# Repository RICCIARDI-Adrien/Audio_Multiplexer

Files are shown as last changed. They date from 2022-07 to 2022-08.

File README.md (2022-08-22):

# Audio multiplexer

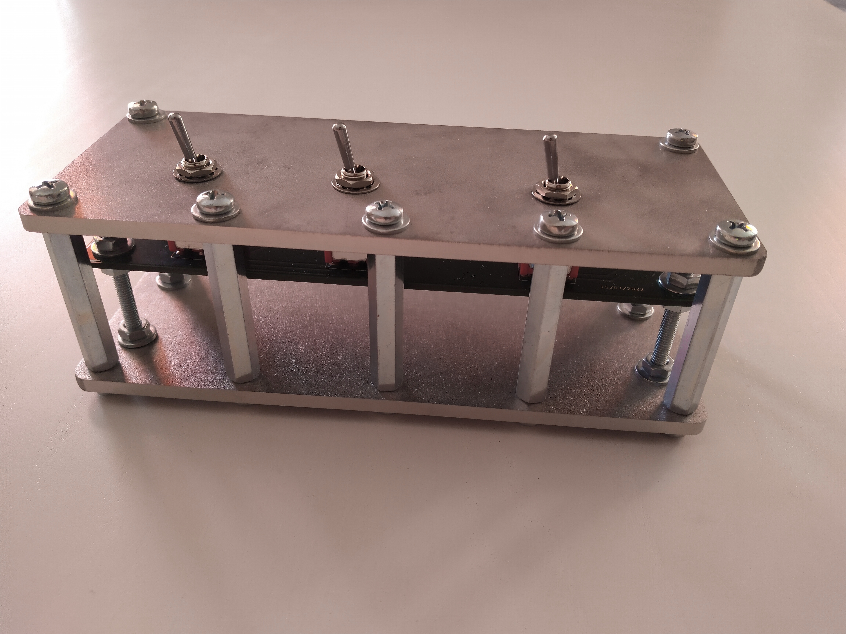
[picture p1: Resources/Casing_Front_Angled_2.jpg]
Casing front angled


## Description

A simple passive multiplexer providing :
* two 3.5mm jack inputs connected to two PC line outputs,
* two 3.5mm jack outputs connected to active speakers and a headset,
* one 3.5mm jack input connected to the headset microphone,
* two 3.5mm jack outputs connected to two PC microphone inputs.

```
                      +------+
             Line out |      | Mic in
     +----------------| PC 1 |<---------------+
     |                |      |                |
     |                +------+                |
     |                                        |
     |                +------+                |
     |       Line out |      | Mic in         |
     |   +------------| PC 2 |<-----------+   |
     |   |            |      |            |   |
     |   |            +------+            |   |
     |   |                                |   |
     v   v                                |   |
  +----------------------------------------------+             
  |              AUDIO MULTIPLEXER               |
  |                                              |
  |  Audio             Audio                Mic  |
  |   in                out                 in   |
  |                                              |
  +----------------------------------------------+
                       |  |                  ^
                       |  |                  |
                +------+  +-----+   +--------+
                |               |   |
                v               v   |
           +----------+      +---------+
           |          |      | Headset |
           | Speakers |      |  with   |
           |          |      |  mic    |
           +----------+      +---------+
```

The multiplexer microphone input is designed to be driven separately in case this is needed later.

## PCB

The PCB has been designed with KiCad 6.0.6.

Naked PCB :
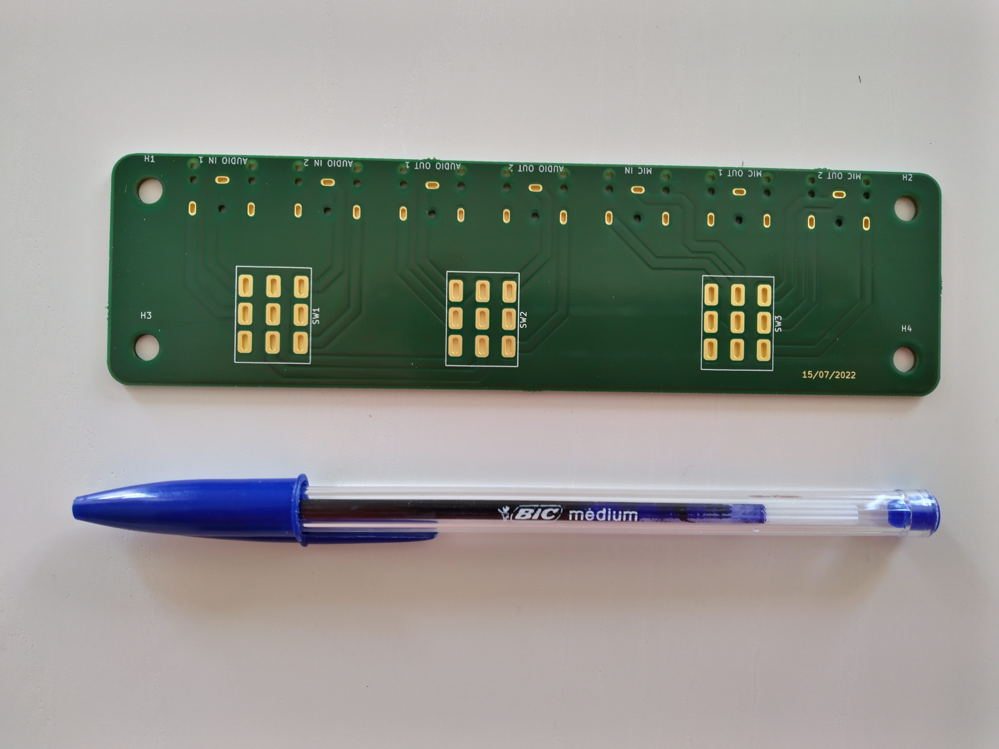
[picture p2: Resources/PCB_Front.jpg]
Naked PCB front view

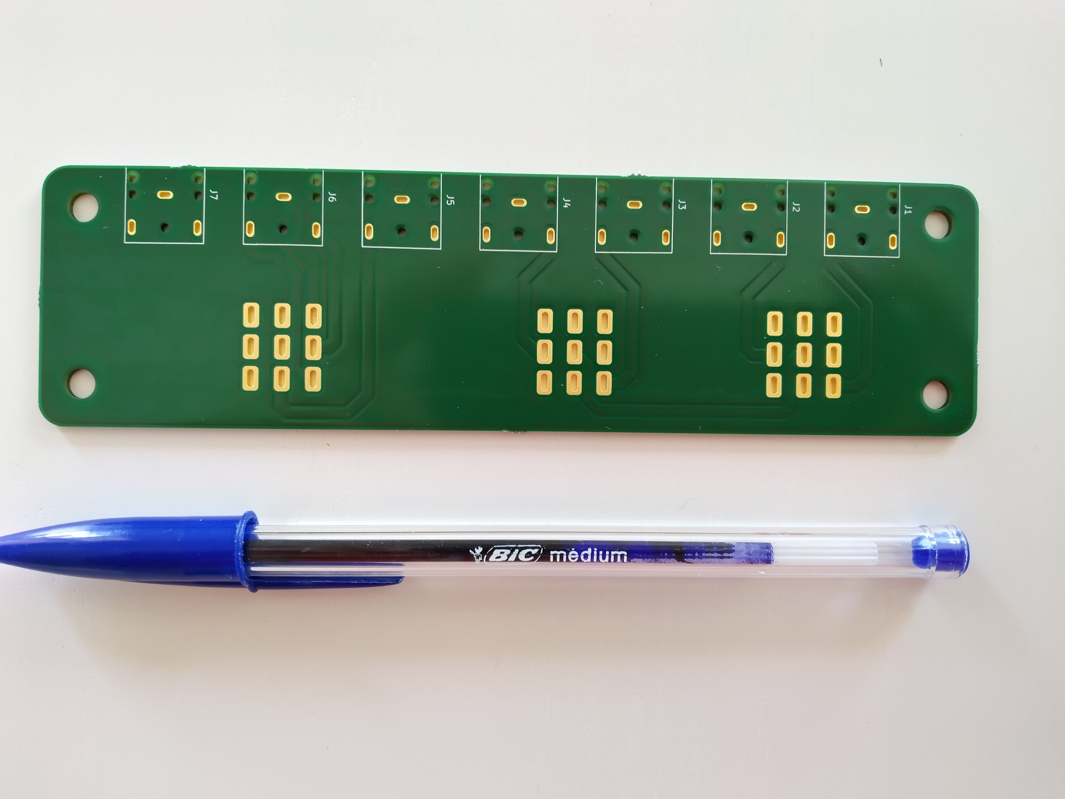
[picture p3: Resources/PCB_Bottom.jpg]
Naked PCB bottom view


Assembled PCB :
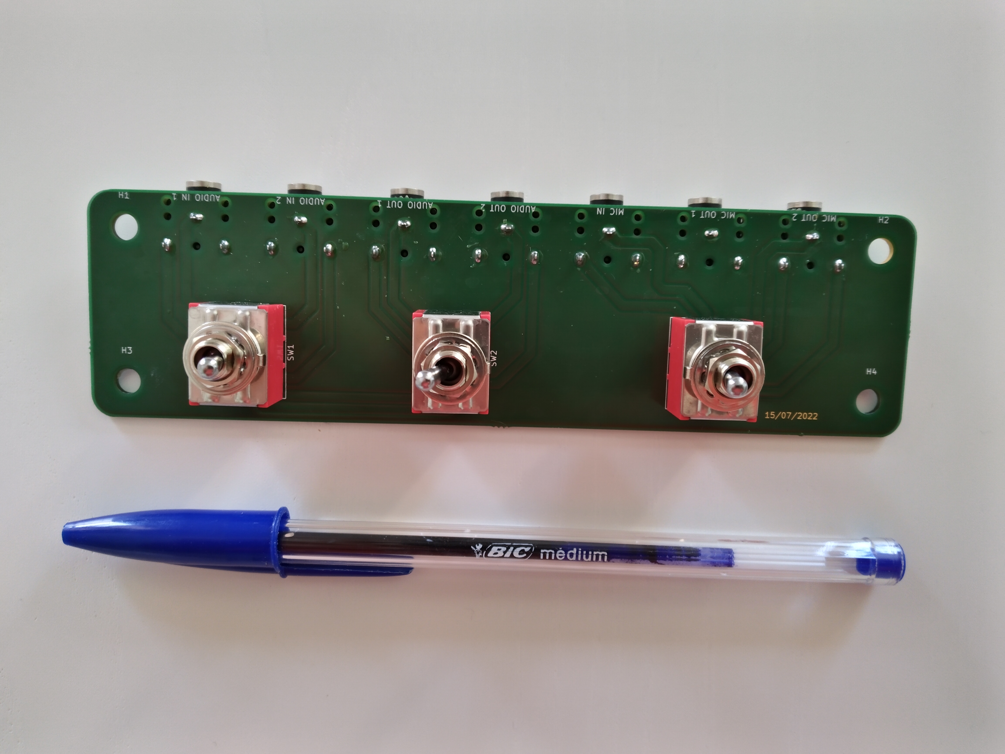
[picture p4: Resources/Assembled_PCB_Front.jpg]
Assembled PCB front view

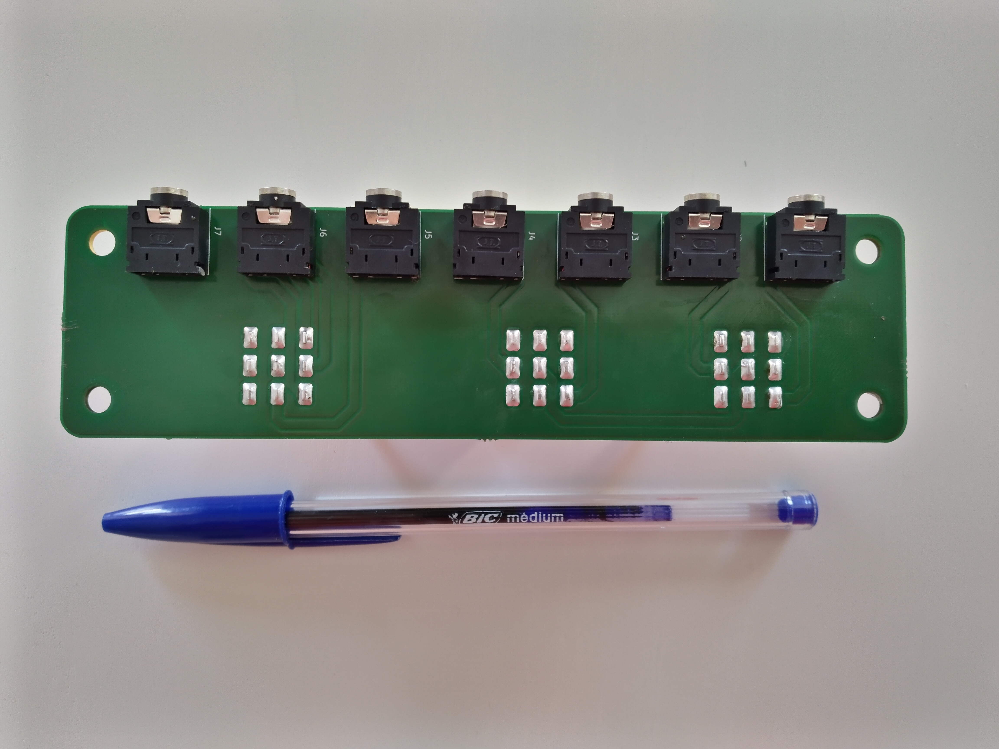
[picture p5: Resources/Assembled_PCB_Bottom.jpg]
Assembled PCB bottom view


## Casing

The casing has been designed with FreeCAD 0.19. The multiple DXF files generated by FreeCAD have been combined using LibreCAD 2.1.3.
The casing has been designed to be laser-cut in a 4-mm thick 304 stainless steel.

Steel plates :
Steel plates

Casing top :
Casing top

Casing bottom :
Casing bottom

Casing front :
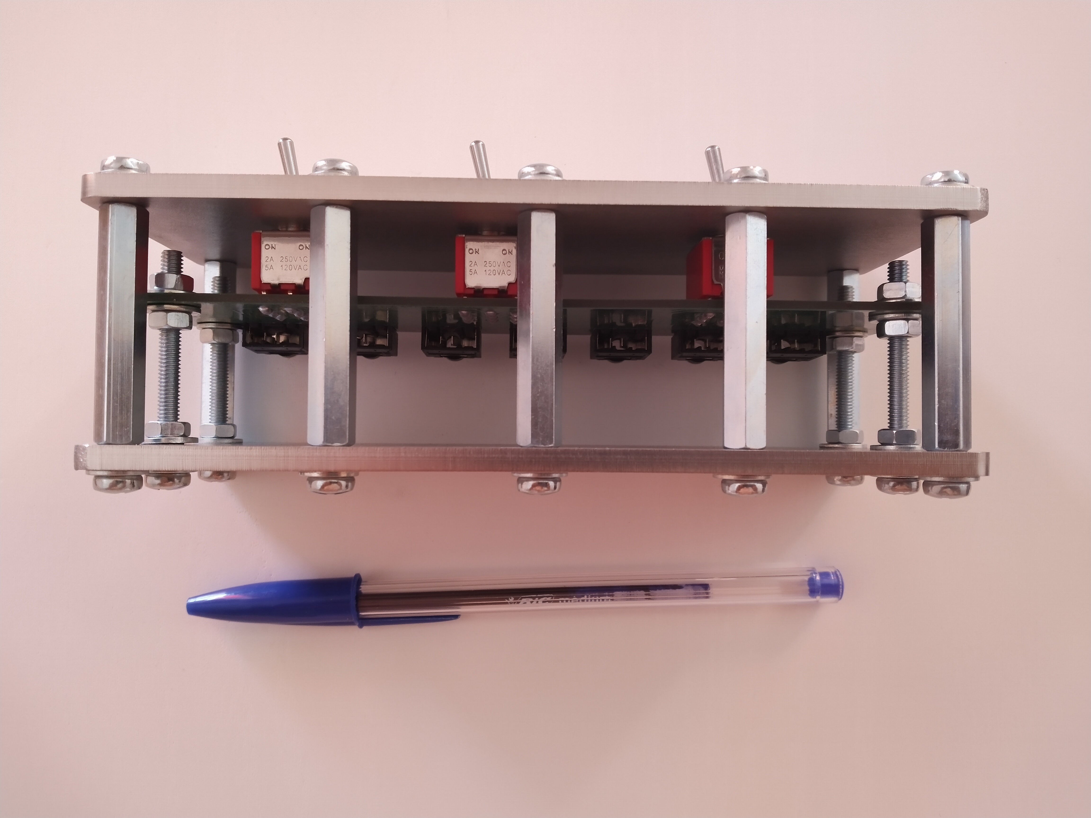
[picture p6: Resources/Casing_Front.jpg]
Casing front


Casing rear :
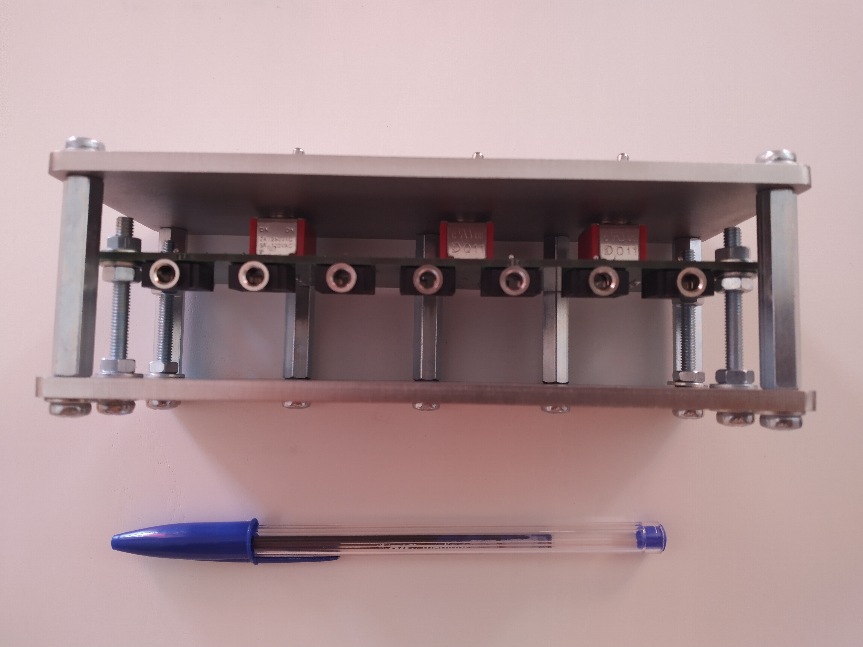
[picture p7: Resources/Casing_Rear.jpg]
Casing rear


Casing front angled :
Casing front angled

Casing rear angled :
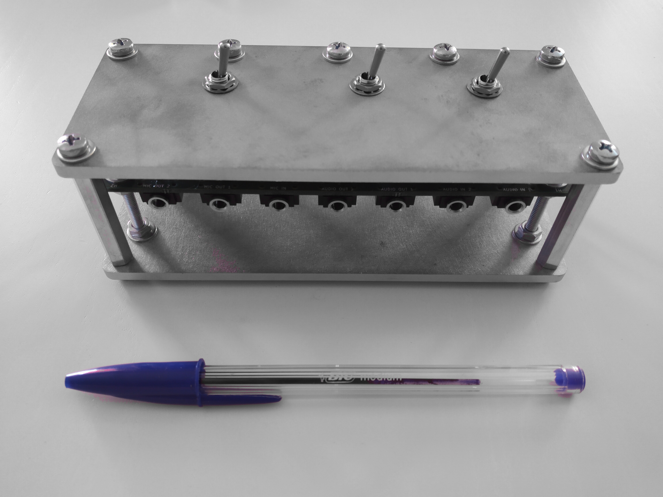
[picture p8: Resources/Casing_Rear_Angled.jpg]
Casing rear angled


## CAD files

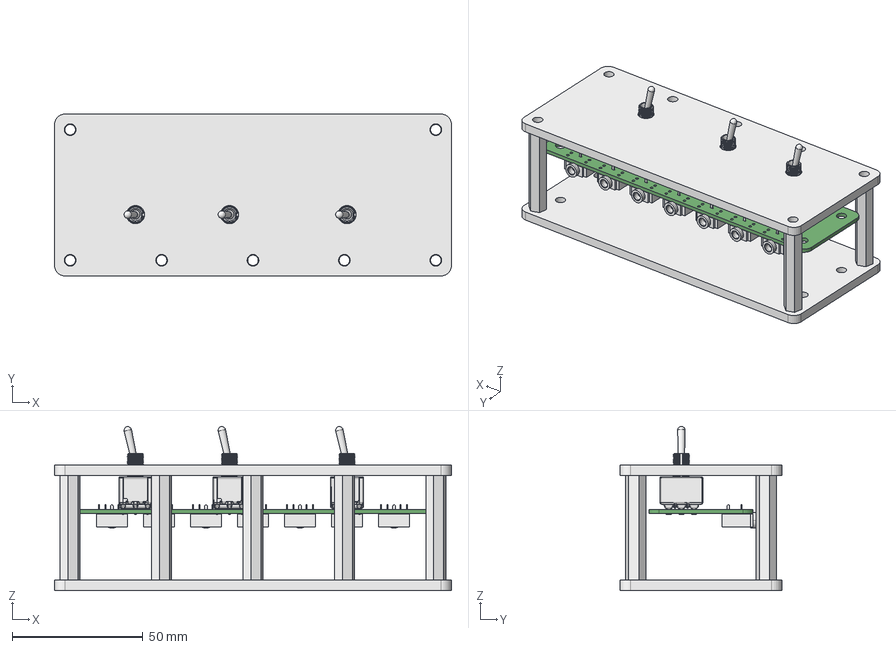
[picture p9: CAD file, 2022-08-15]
Casing/Casing.FCStd
152.0 x 62.0 x 62.8 mm
Top_Plate
Audio_Multiplexer PCB
Bottom_Plate
Hex_Standoff_1 x 7

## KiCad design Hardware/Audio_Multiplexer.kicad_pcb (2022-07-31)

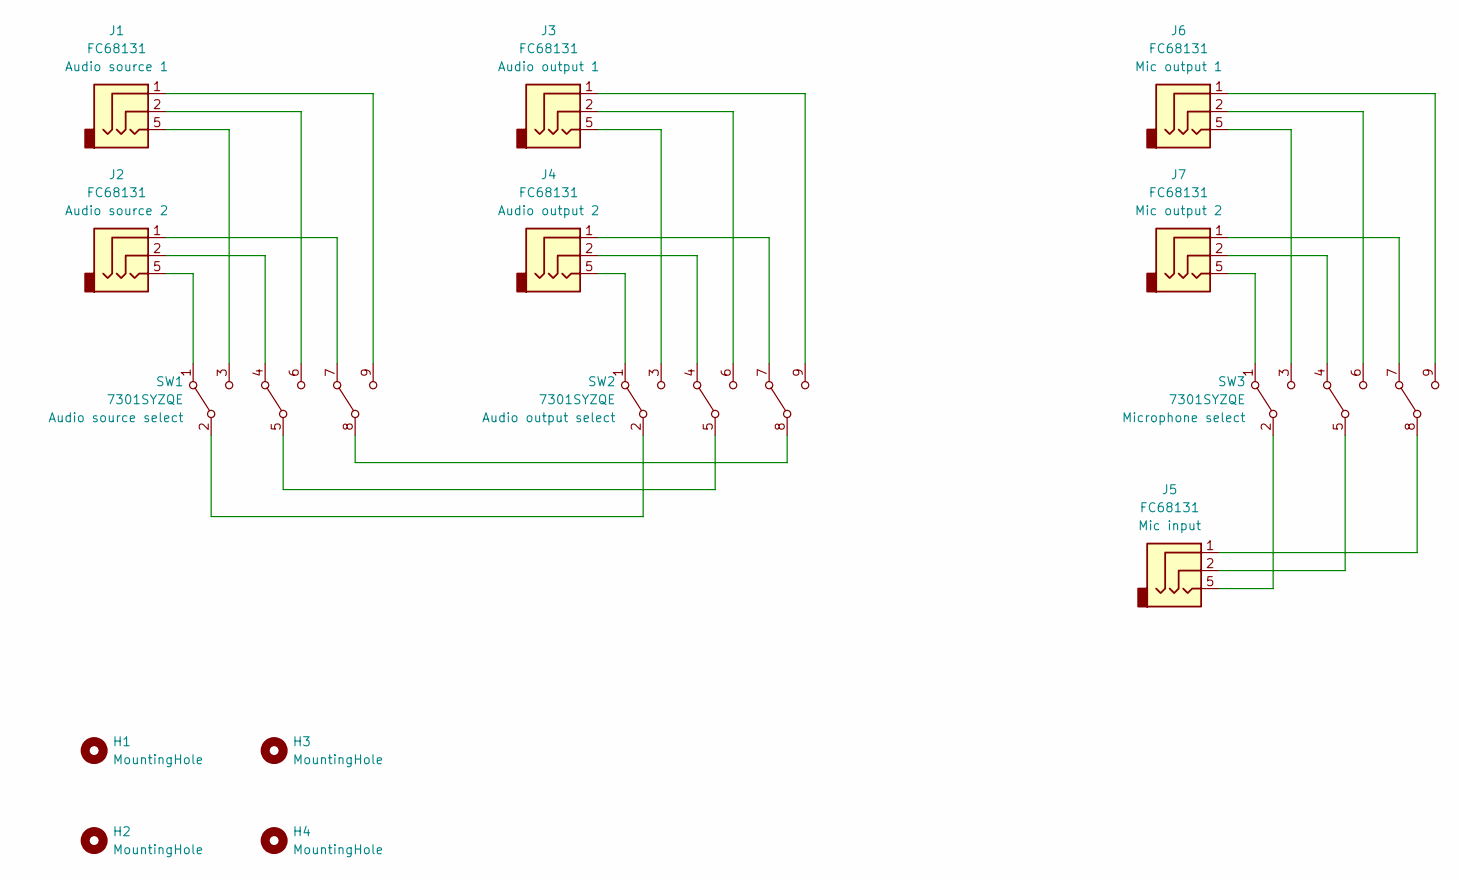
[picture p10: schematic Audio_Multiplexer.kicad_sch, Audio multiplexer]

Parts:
H1, H2, H3, H4: MountingHole; MountingHole_4.5mm
J1, J2, J3, J4, J5, J6, J7: FC68131
SW1, SW2, SW3: 7301SYZQE

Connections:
unnamed: J1.1, SW1.9
unnamed: J1.2, SW1.6
unnamed: J1.5, SW1.3
unnamed: J2.1, SW1.7
unnamed: J2.2, SW1.4
unnamed: J2.5, SW1.1
unnamed: J3.1, SW2.9
unnamed: J3.2, SW2.6
unnamed: J3.5, SW2.3
unnamed: J4.1, SW2.7
unnamed: J4.2, SW2.4
unnamed: J4.5, SW2.1
unnamed: J5.1, SW3.8
unnamed: J5.2, SW3.5
unnamed: J5.5, SW3.2
unnamed: J6.1, SW3.9
unnamed: J6.2, SW3.6
unnamed: J6.5, SW3.3
unnamed: J7.1, SW3.7
unnamed: J7.2, SW3.4
unnamed: J7.5, SW3.1
unnamed: SW1.2, SW2.2
unnamed: SW1.5, SW2.5
unnamed: SW1.8, SW2.8

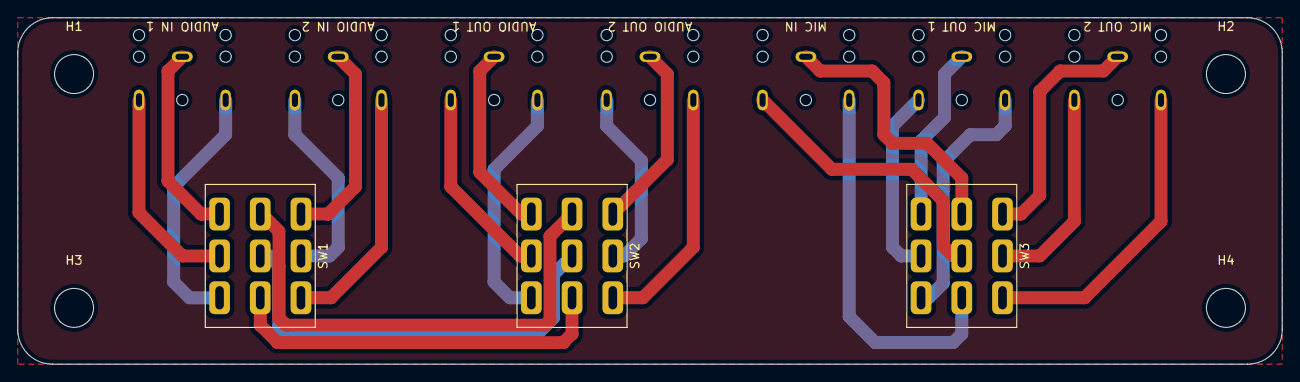
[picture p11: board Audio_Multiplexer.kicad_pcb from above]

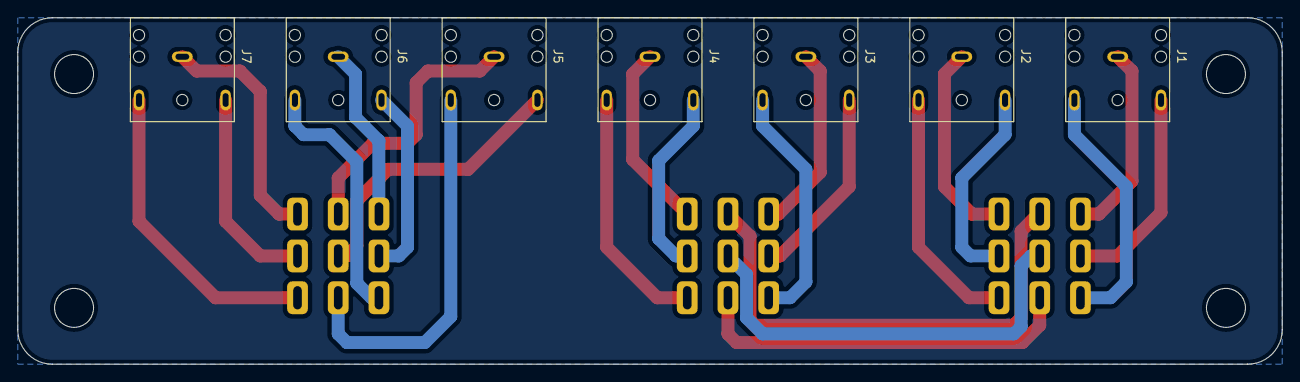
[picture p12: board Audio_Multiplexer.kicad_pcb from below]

Board: 2 copper layers, 146.0 x 40.0 mm, 14 parts (7 on the bottom side), 24 nets.

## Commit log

2022-07-15 Started schematic. Added FC68131 audio jack symbol, footprint and 3D model.
    [Audio_Multiplexer.kicad_pcb, Audio_Multiplexer.kicad_sch]
2022-07-15 Added 7301SYZQE switch symbol, footprint and 3D model.
2022-07-15 Finished schematic. Added audio and microphone blocks.
    [Audio_Multiplexer.kicad_sch]
2022-07-15 Placed all components and routed the circuit.
    [Audio_Multiplexer.kicad_pcb, Audio_Multiplexer.kicad_sch]
2022-07-15 Rounded PCB corners to make them more robust.
    [Audio_Multiplexer.kicad_pcb]
2022-07-15 Added copper planes to PCB top and bottom layers in order to decrease the amount of copper to remove. This simplifies the PCB manufacturing process.
    [Audio_Multiplexer.kicad_pcb]
2022-07-15 Added jack connectors label silkscreen texts to the PCB. Also added the design date.
    [Audio_Multiplexer.kicad_pcb]
2022-07-15 Set PCB grid origin and drill grid origin.
    [Audio_Multiplexer.kicad_pcb]
2022-07-17 Decreased PCB width by one millimeter so the casing can be 2 millimeters large on each side.
    [Audio_Multiplexer.kicad_pcb]
2022-07-17 Started casing design. Added a generic plate sketch.
    [Casing.FCStd]
2022-07-31 Improved a PCB trace to make it more straight.
    [Audio_Multiplexer.kicad_pcb]
2022-08-01 Finished casing top plate.
    [Casing.FCStd]
2022-08-07 Added the hex standoff model to the casing.
    [Casing.FCStd]
2022-08-07 Aligned casing top plate with PCB.
    [Casing.FCStd]
2022-08-07 Added all casing hex standoffs and aligned them.
    [Casing.FCStd]
2022-08-07 Aligned casing bottom plate.
    [Casing.FCStd]
2022-08-15 Added the PCB fixation holes to the casing bottom plate.
    [Casing.FCStd]
2022-08-15 Added top plate and bottom plate casing drawings to be able to export them as DXF.
    [Casing.FCStd]
2022-08-15 Improved casing top plate sketch and increased its length and width by 2mm each to be able to cut the plate in 4-mm thick steel with a laser.
    [Casing.FCStd]
2022-08-15 Improved casing bottom plate sketch and increased its length and width by 2mm each to be able to cut the plate in 4-mm thick steel with a laser.
    [Casing.FCStd]
2022-08-15 Added PCB and casing information to the README.md. Also added naked PCB and assembled PCB pictures.
